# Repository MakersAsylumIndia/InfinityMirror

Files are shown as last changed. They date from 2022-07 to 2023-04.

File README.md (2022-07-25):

# infinity
Circular infinity Mirror project using addressable LED's, based on the [Infinity Mirror designed by Kevin Osbock at WyoLum](https://github.com/wyolum/infinity). Can also be ued as an awesome Coaster, if a 5V source can be embedded in it.

- The /fabricate folder has a FreeCAD file that is parametric - you can choose some of the major dimensions.
- The default settings is for a 200 mm long LED strip.
- The layer stack consists of (top to bottom):
-- Front bezel, which is optional, but gives a better visual result and protects the front mirror.
-- Front Mirror, which is one way or transluscent or whatever is the appropriate terminology (50% transmittance and 50% reflectance).
-- A stack of rings, whose total height is equal or greater than the width of the LED strip.
-- Back mirror, 100% transmittance.
-- Back support plate.
-- A stack of plates to enclose the microcontroller board. The cutout in the plates, and the number of plates needed depends on the size and height of the microcontroller PCB.
-- A final back cover plate. 

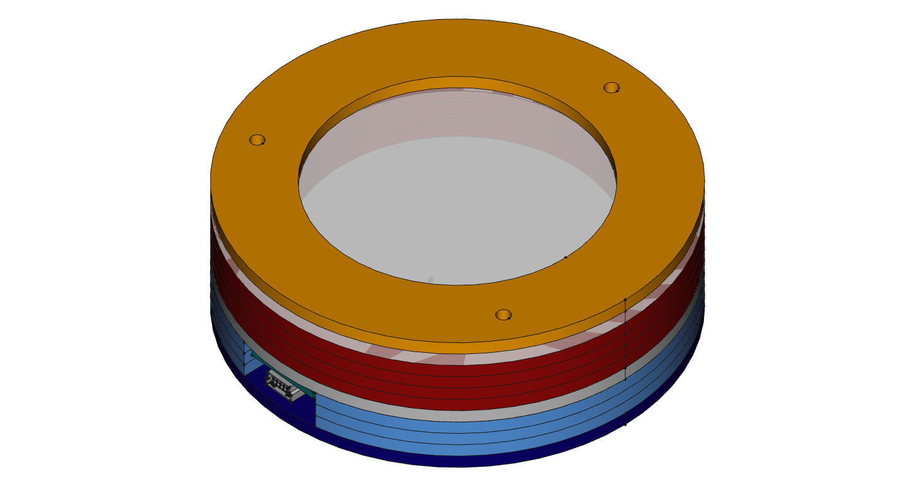
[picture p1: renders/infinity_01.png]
Infinity_Mirror_01

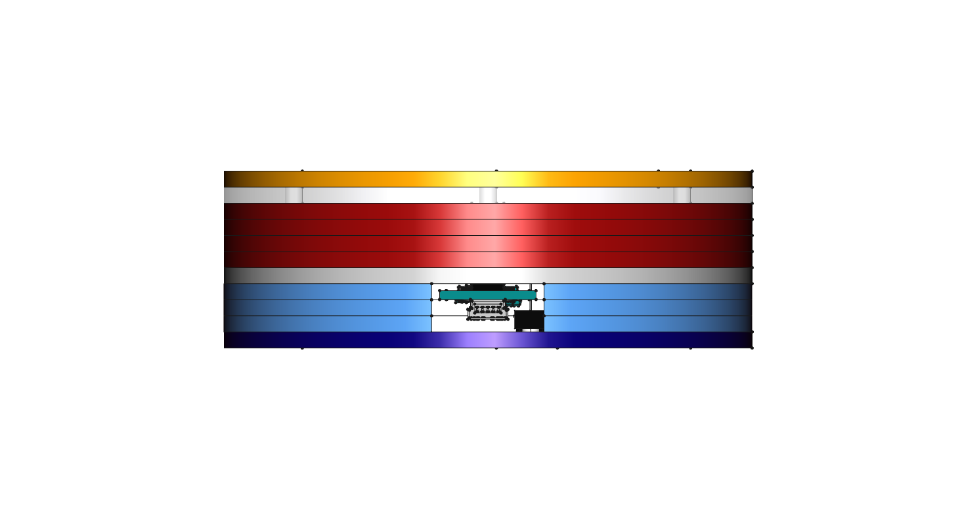
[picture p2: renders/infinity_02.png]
Infinity_Mirror_02

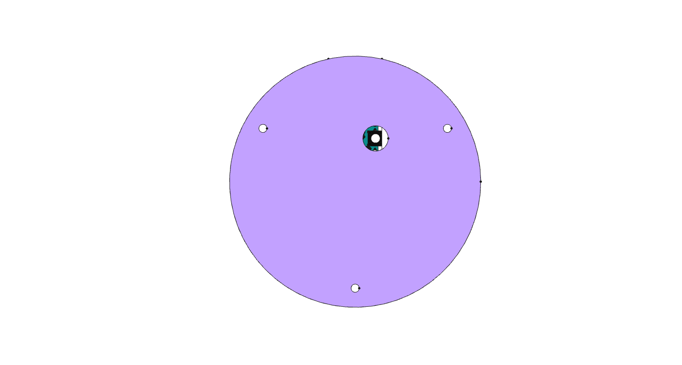
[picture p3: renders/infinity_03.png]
Infinity_Mirror_03


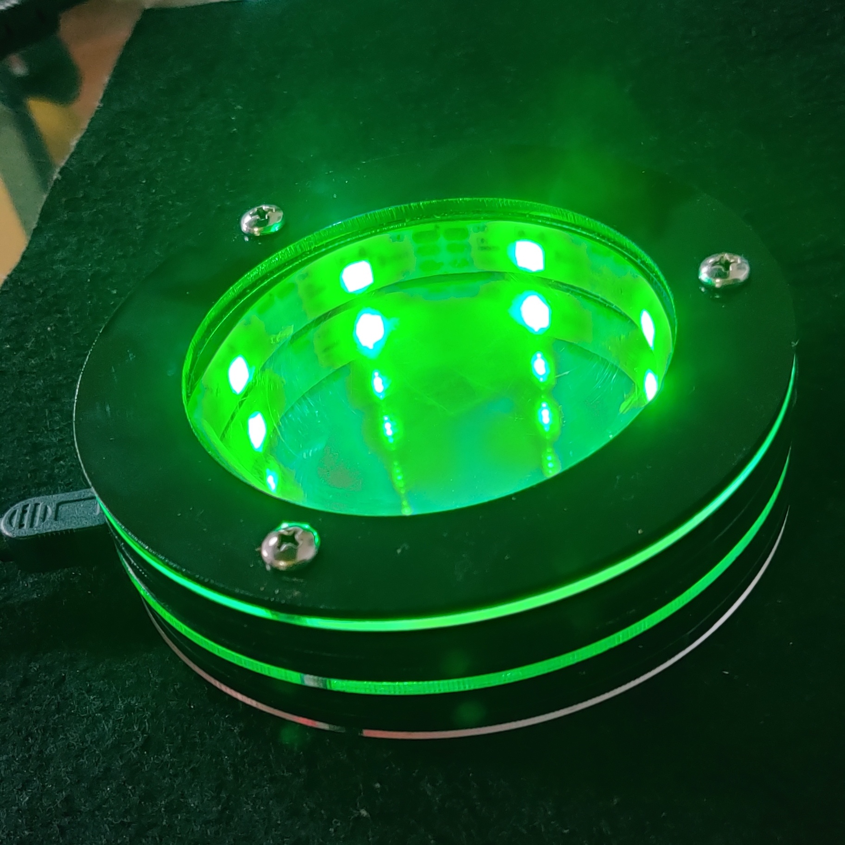
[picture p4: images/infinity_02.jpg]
Infinity_Mirror_04

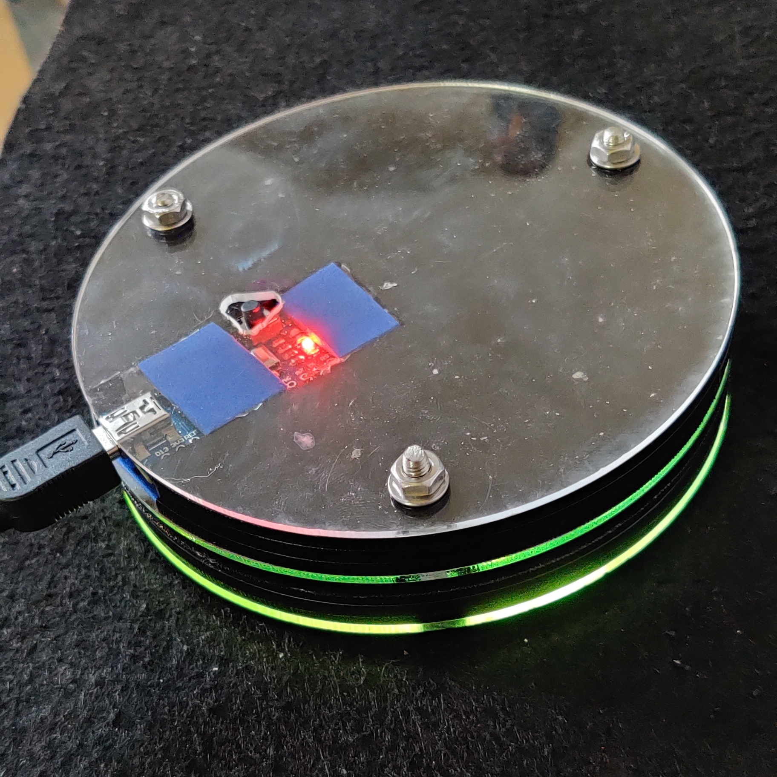
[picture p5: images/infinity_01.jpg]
Infinity_Mirror_05


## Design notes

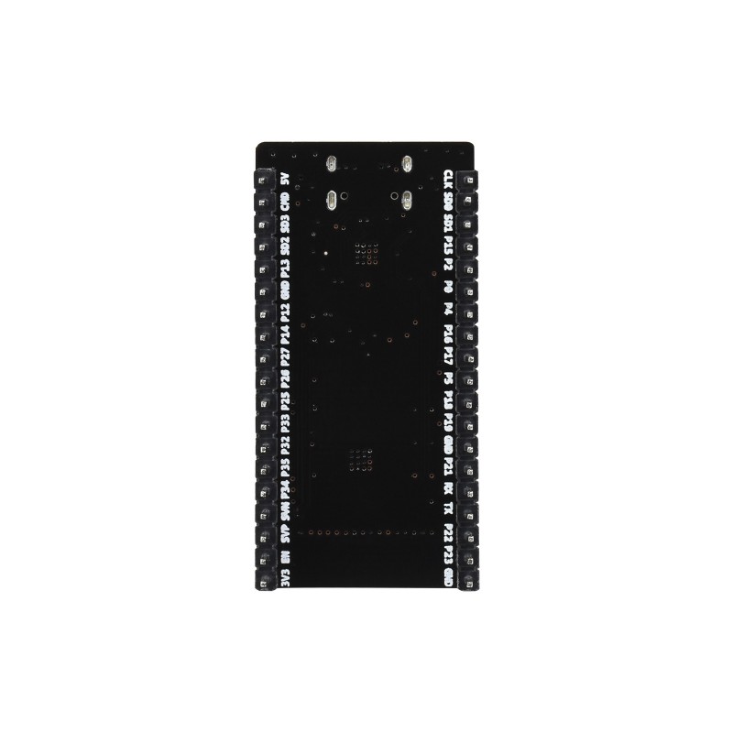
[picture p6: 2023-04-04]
kicad/datasheets/nodemcu-32s-5.jpg

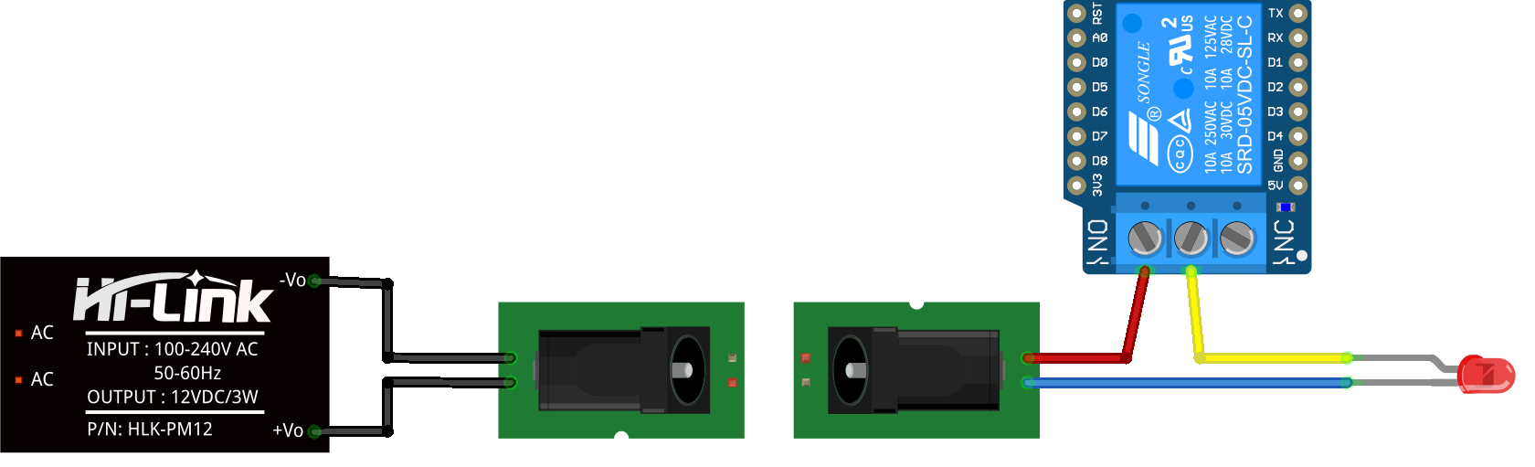
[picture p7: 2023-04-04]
kicad/datasheets/IoT_lamp_12V_LED_02.png

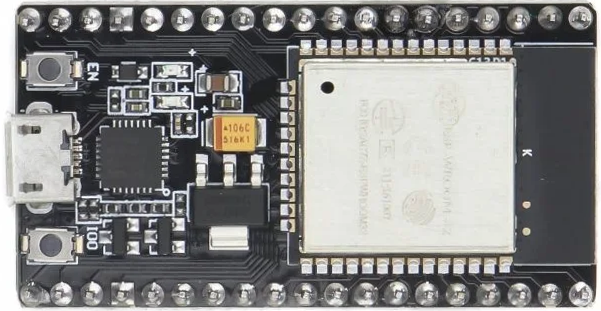
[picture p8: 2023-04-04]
kicad/datasheets/ESP-WROOM-32-MCU-Module3-768x768-1.png

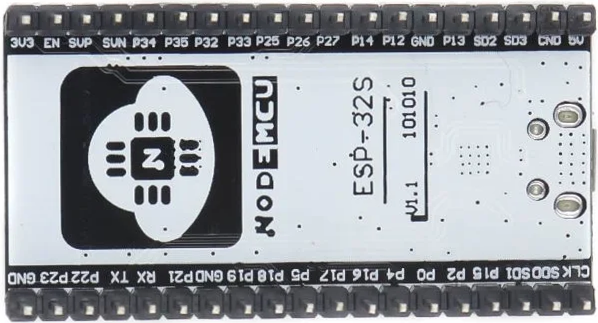
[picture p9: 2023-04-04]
kicad/datasheets/ESP-WROOM-32-MCU-Module4-768x768-1.png

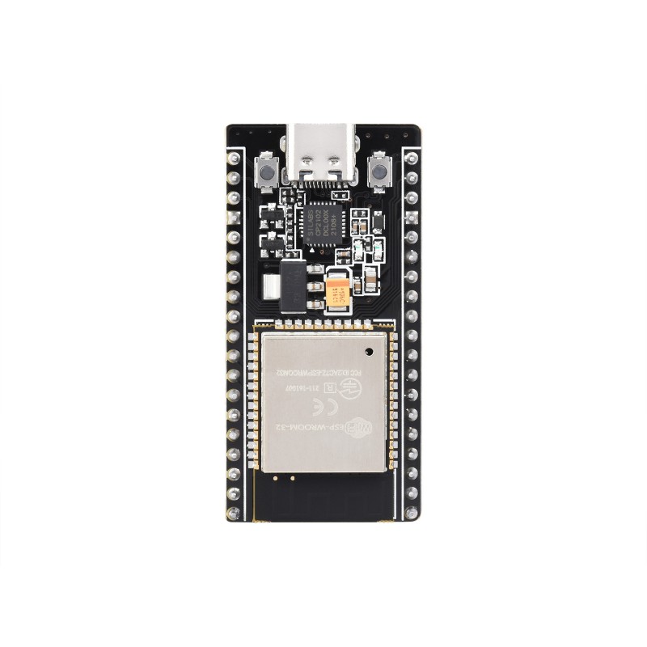
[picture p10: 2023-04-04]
kicad/datasheets/nodemcu-32s-4_4.jpg

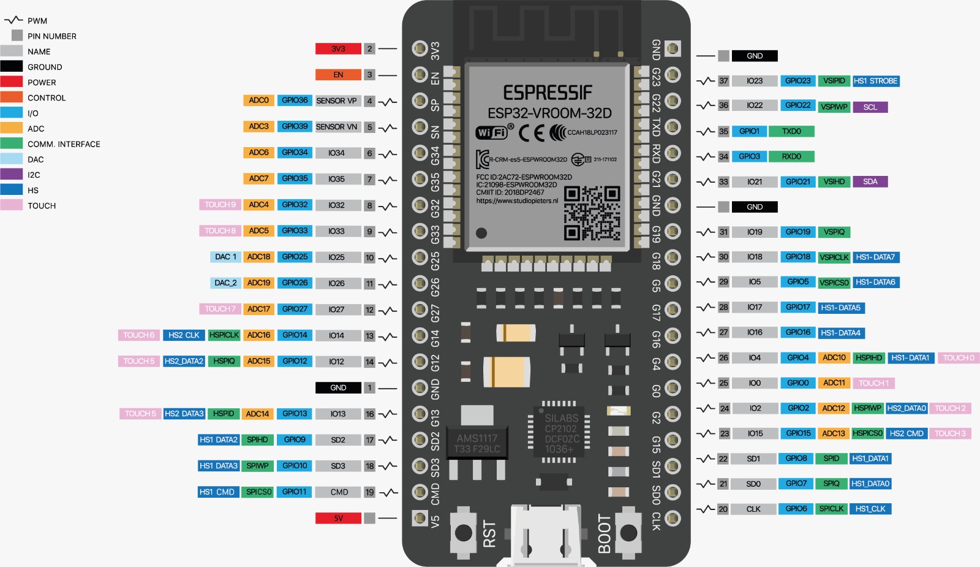
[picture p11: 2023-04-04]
kicad/datasheets/ESP32_VROOM_32D.jpeg

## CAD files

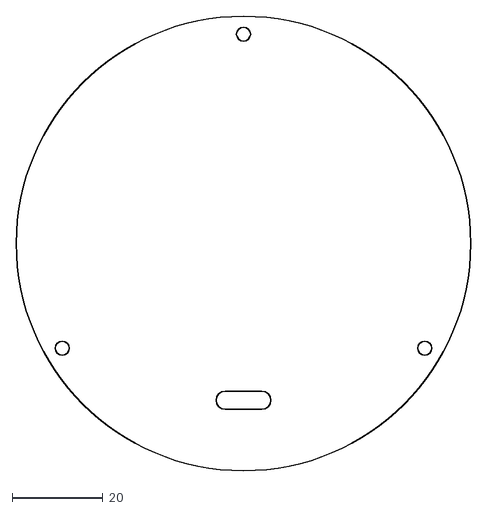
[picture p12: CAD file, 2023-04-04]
fabricate/Infinity_02_DXF/infinity_02-mirror_main.dxf
100.0 x 100.0

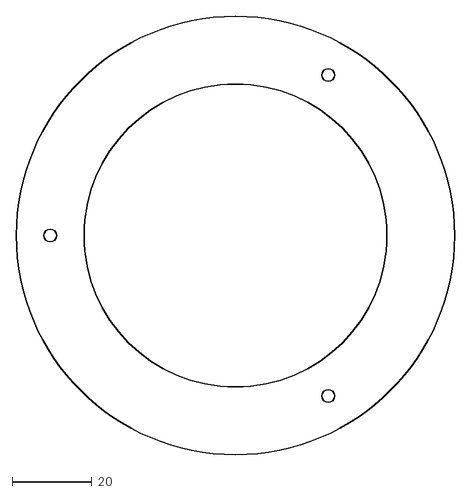
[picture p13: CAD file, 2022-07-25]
fabricate/DXF_anool/bezel.dxf
110.0 x 110.0

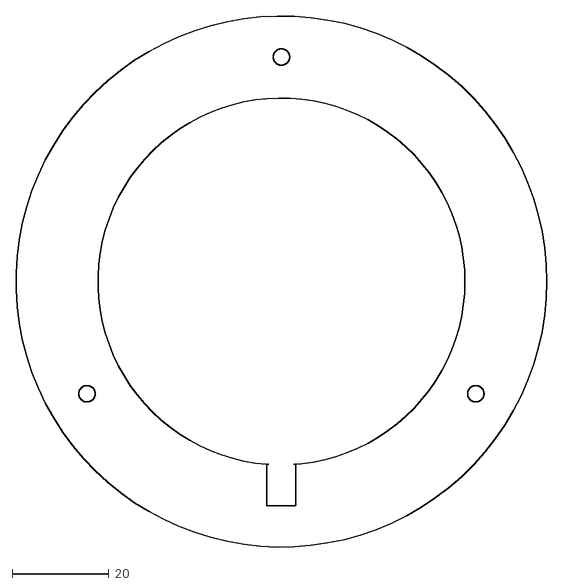
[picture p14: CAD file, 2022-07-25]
fabricate/DXF_SVG_kevin/spacer.dxf
110.0 x 110.0

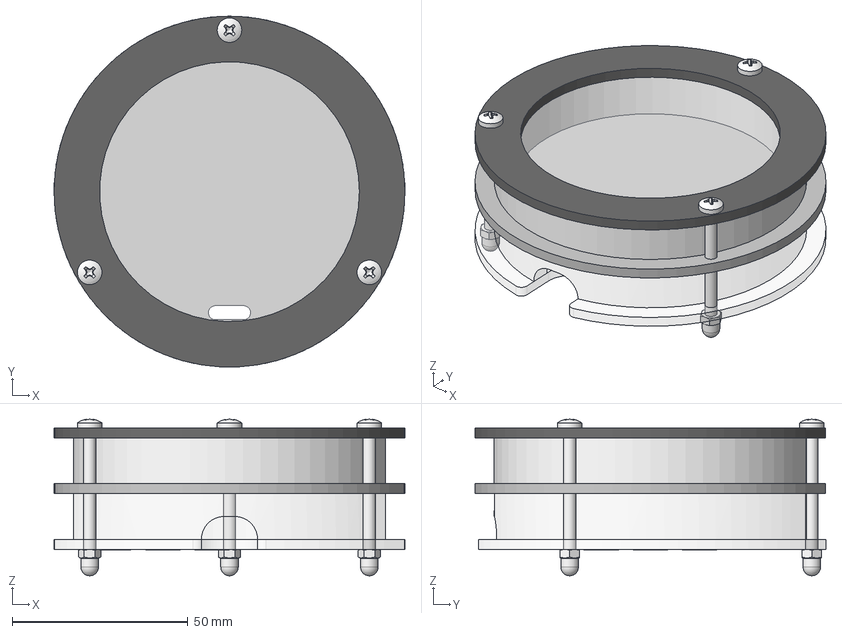
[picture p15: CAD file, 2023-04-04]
fabricate/infinity_02.FCStd
100.0 x 99.9 x 44.6 mm
PCB_lower_spacer
Mirror
Upper_spacer
Mirror_one_way
Front_bezel
Back_cover
Copper_pads
(M3.5)x38-Screw
(M3.5)x38-Screw279
(M3.5)x38-Screw280
M3-Nut
M3-Nut433
M3-Nut434

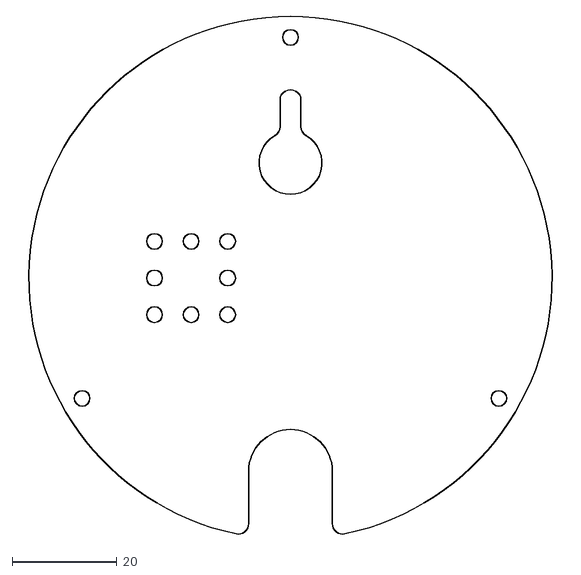
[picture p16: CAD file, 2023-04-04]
fabricate/Infinity_02_DXF/infinity_02-Back_cover.dxf
104.8 x 99.0

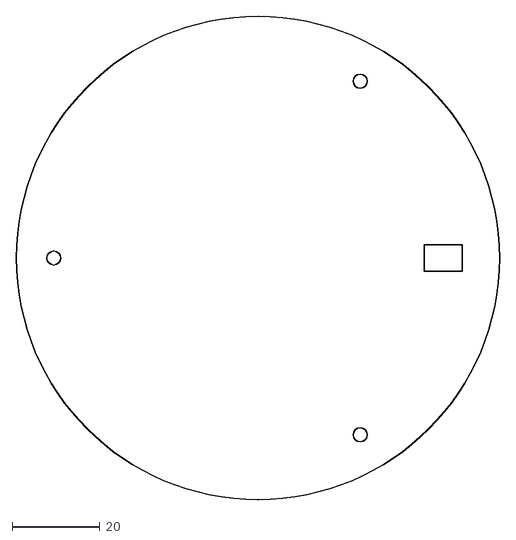
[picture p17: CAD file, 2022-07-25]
fabricate/DXF_anool/back_mirror.dxf
110.0 x 110.0

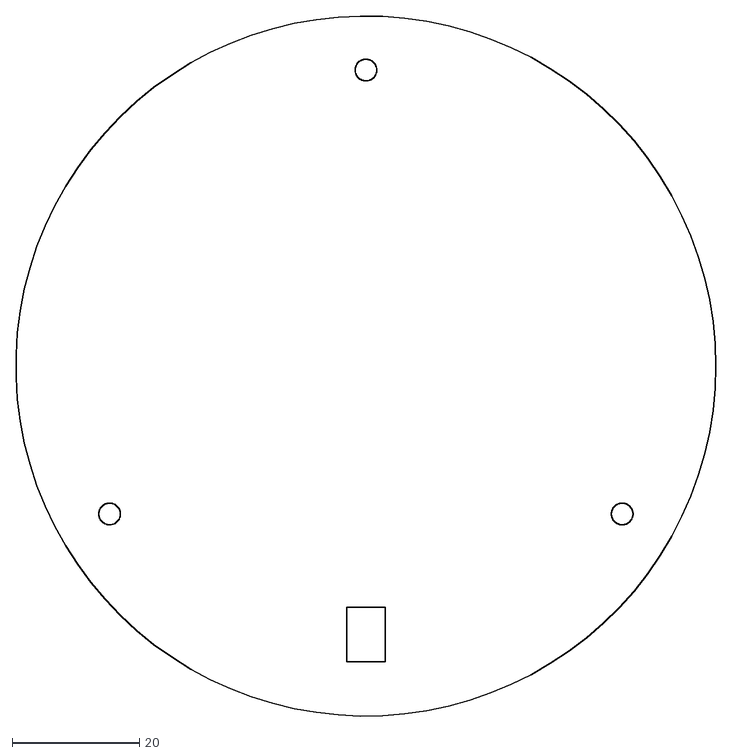
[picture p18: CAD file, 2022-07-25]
fabricate/DXF_SVG_kevin/back_mirror.dxf
110.0 x 110.0

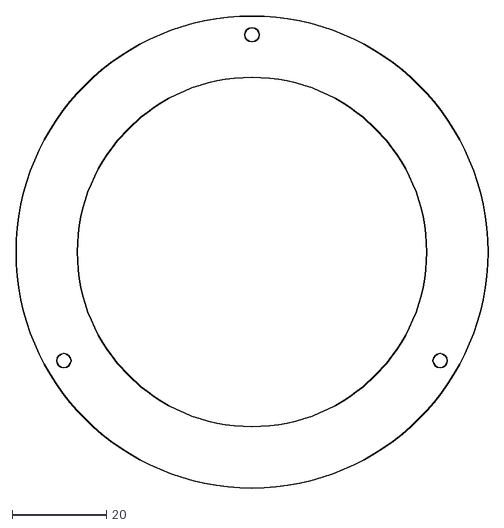
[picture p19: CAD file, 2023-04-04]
fabricate/Infinity_02_DXF/infinity_02-Front_bezel.dxf
100.0 x 100.0

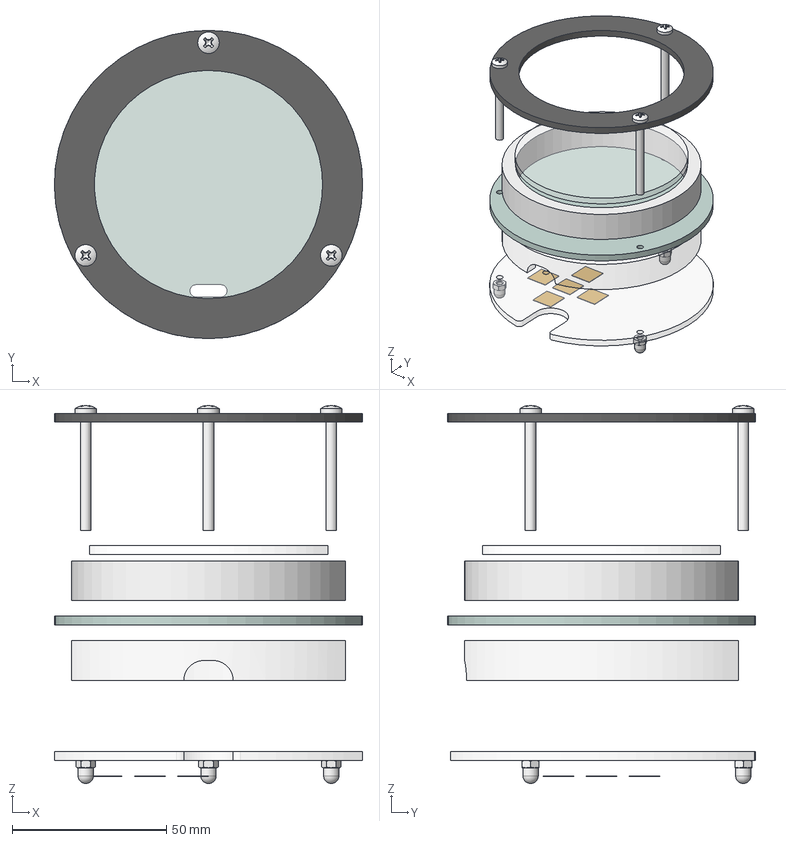
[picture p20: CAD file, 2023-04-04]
fabricate/infinity_02_exploded.FCStd
100.0 x 100.0 x 122.6 mm
PCB_lower_spacer
Mirror
Upper_spacer
Mirror_one_way
Front_bezel
Back_cover
Copper_pads
(M3.5)x38-Screw
(M3.5)x38-Screw309
(M3.5)x38-Screw310
M3-Nut
M3-Nut447
M3-Nut448

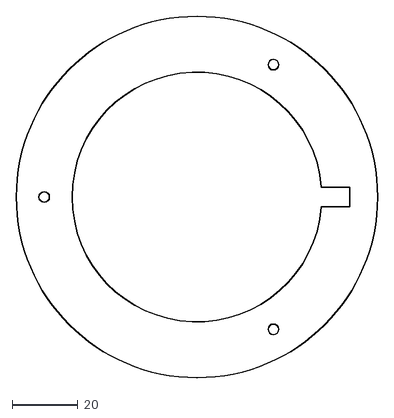
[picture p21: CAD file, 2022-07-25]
fabricate/DXF_anool/spacer_3nos.dxf
110.0 x 110.0

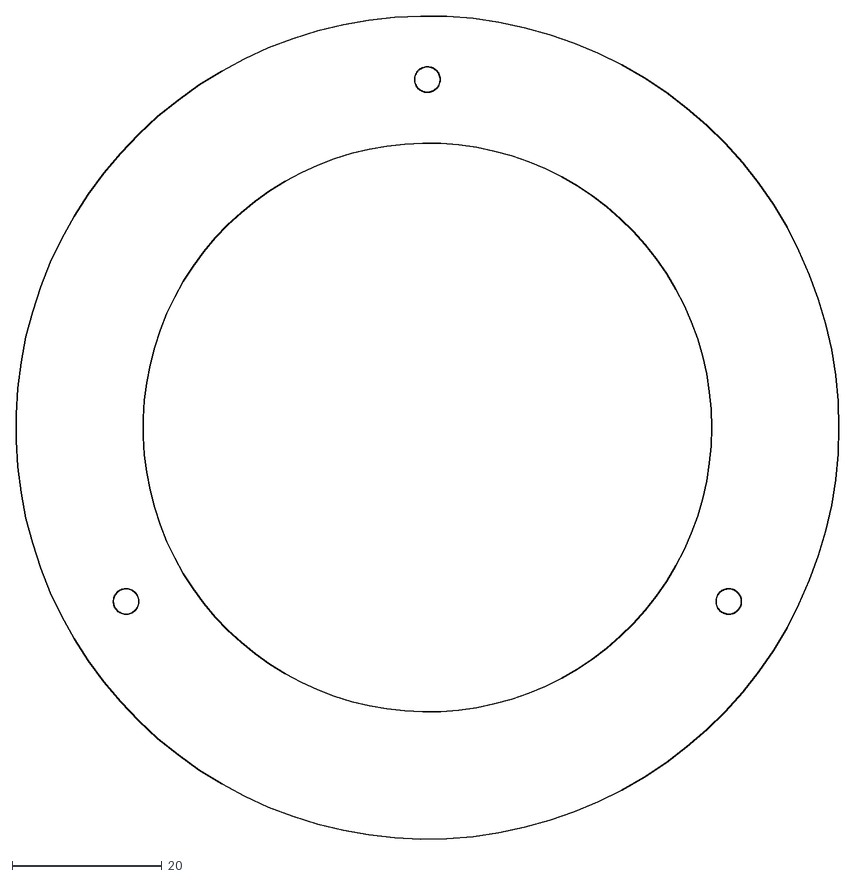
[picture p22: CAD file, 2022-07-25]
fabricate/DXF_SVG_kevin/bezel.dxf
110.0 x 110.0

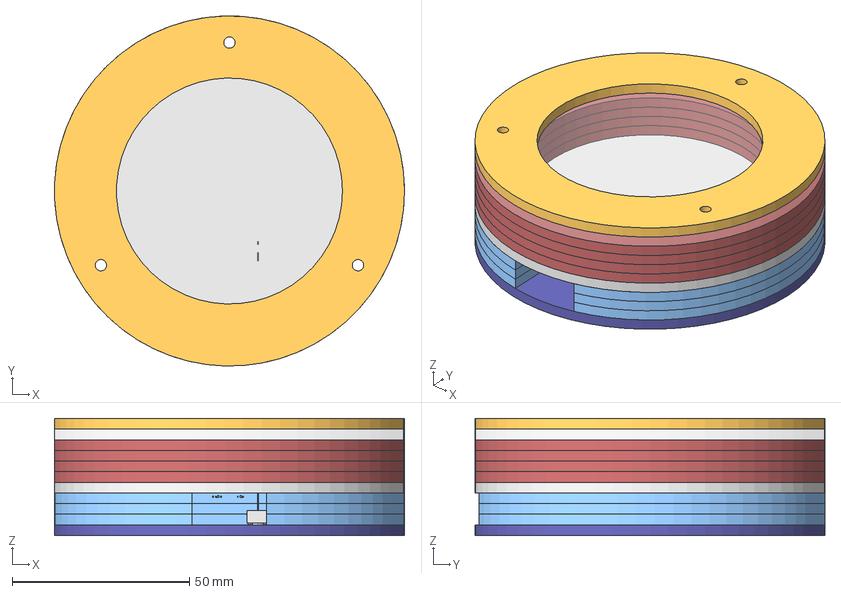
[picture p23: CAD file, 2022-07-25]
fabricate/infinity_01.FCStd
98.7 x 98.7 x 33.0 mm
front_mirror_50%
spacer01
bezel
spacer02
spacer03
back_mirror_100%
arduino_micro_back001
arduino_micro_back002
Component3(Mirror) x 15
Component5(Mirror) x 3
Component5(Mirror) (1) x 3
b3f-6000
spacer04
arduino_micro_back003
back

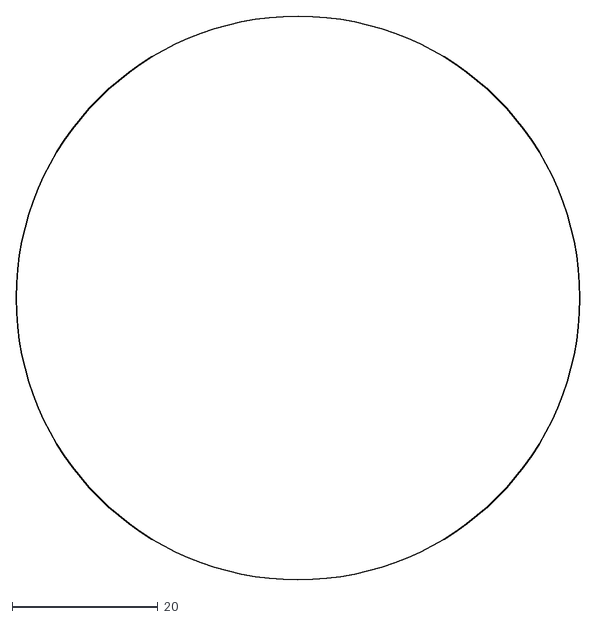
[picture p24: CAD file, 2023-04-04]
fabricate/Infinity_02_DXF/infinity_02-mirror_one_way.dxf
77.4 x 77.4

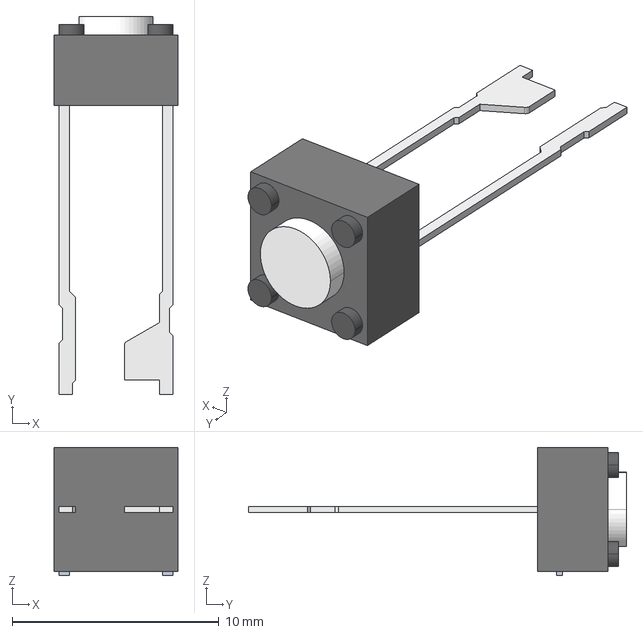
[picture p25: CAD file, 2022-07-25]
fabricate/b3f-6000.step
6.00 x 18.3 x 6.20 mm

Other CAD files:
fabricate/DXF_anool/mirror_2nos.dxf
fabricate/DXF_SVG_kevin/arduino_micro_back.dxf
fabricate/arduino_nano.step
fabricate/DXF_anool/arduino_nano_back.dxf
fabricate/DXF_SVG_kevin/front_mirror.dxf
fabricate/DXF_anool/arduino_micro_back.dxf
fabricate/DXF_anool/back.dxf
fabricate/archive/DXF_SVG_kevin/arduino_micro_back.dxf
fabricate/archive/DXF_SVG_kevin/front_mirror.dxf
fabricate/archive/DXF_anool/arduino_micro_back.dxf
fabricate/archive/DXF_anool/arduino_nano_back.dxf
fabricate/archive/DXF_anool/back.dxf
fabricate/archive/DXF_anool/mirror_2nos.dxf
fabricate/archive/arduino_nano.step

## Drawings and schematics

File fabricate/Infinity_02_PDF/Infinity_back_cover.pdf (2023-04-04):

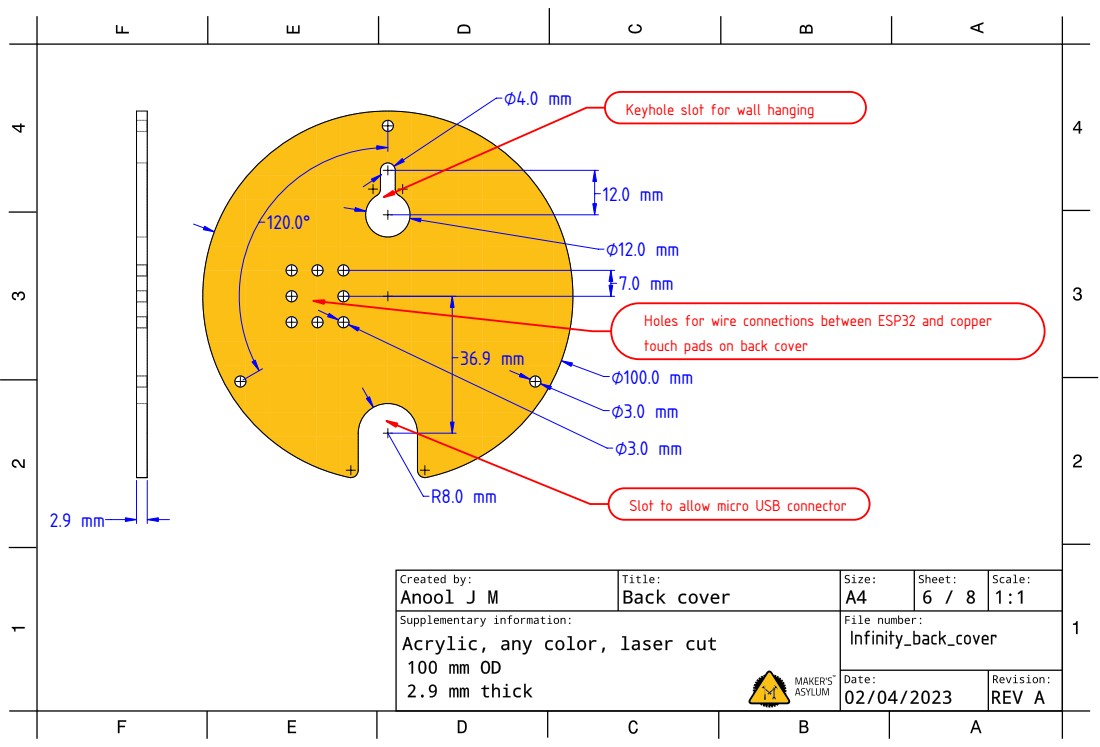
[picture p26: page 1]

Keyhole slot for wall hanging

Holes for wire connections between ESP32 and copper
touch pads on back cover

Slot to allow micro USB connector

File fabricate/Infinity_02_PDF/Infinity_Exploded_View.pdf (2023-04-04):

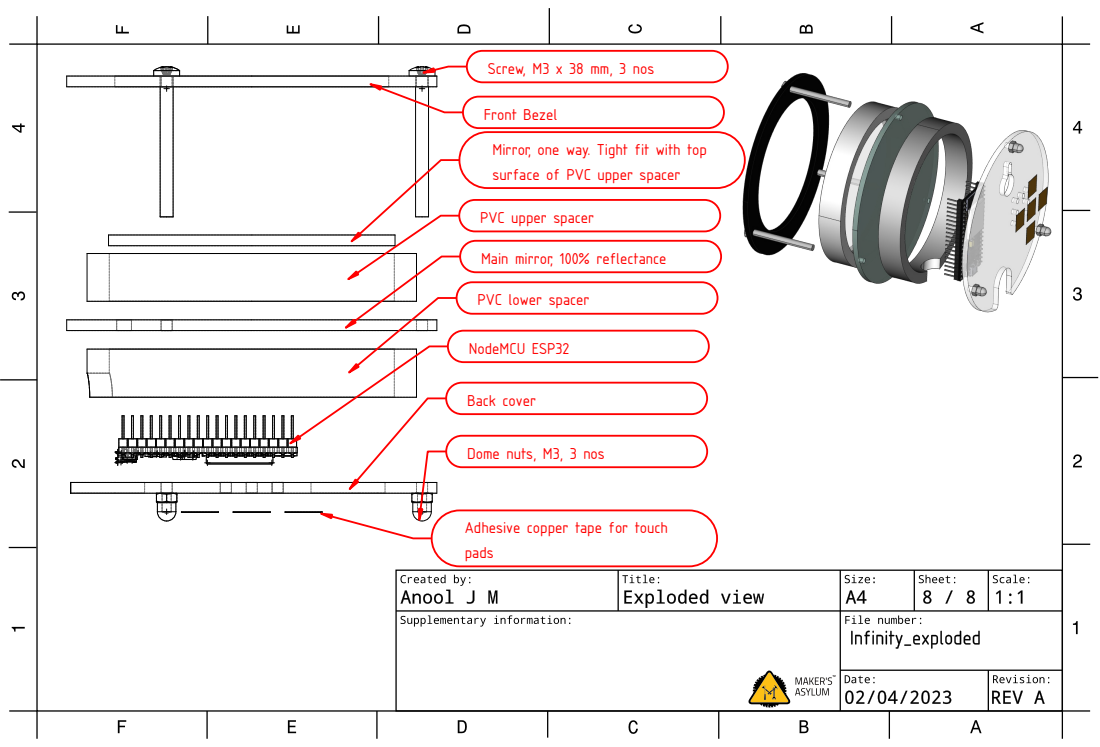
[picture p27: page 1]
NodeMCU ESP32; Back cover

Screw, M3 x 38 mm, 3 nos
Front Bezel
Mirror, one way. Tight fit with top
surface of PVC upper spacer
PVC upper spacer
Main mirror, 100% reflectance
PVC lower spacer

Dome nuts, M3, 3 nos

Adhesive copper tape for touch
pads

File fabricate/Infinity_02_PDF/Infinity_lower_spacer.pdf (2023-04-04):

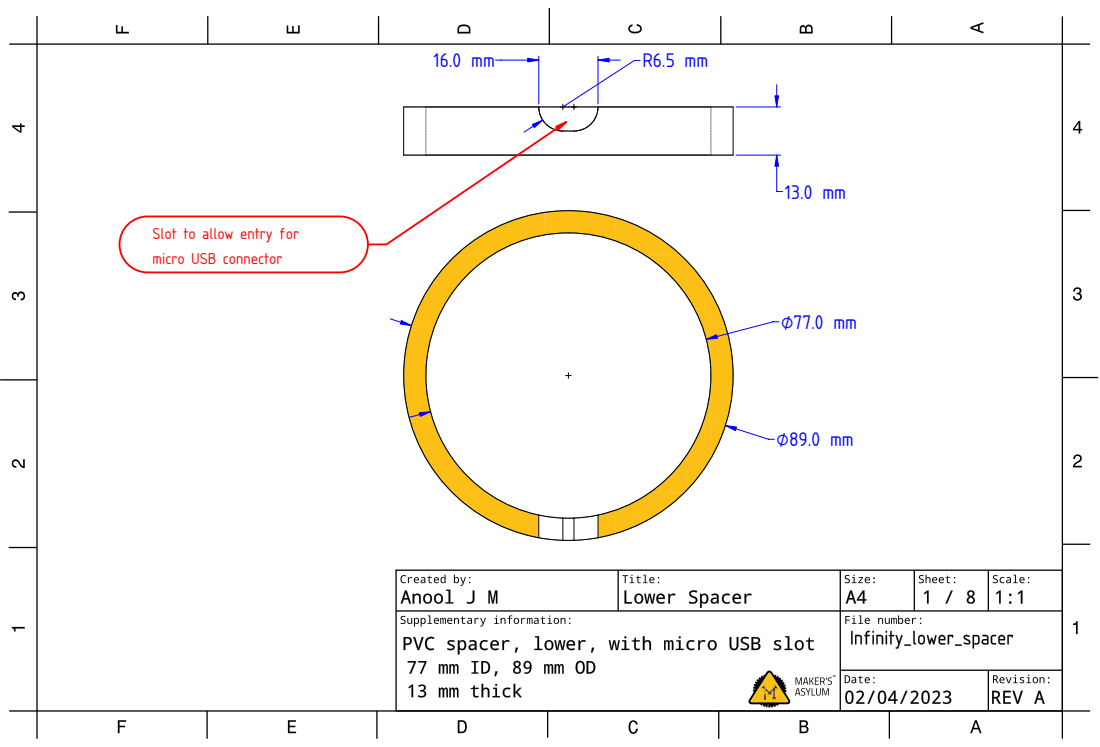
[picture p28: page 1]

Slot to allow entry for
micro USB connector

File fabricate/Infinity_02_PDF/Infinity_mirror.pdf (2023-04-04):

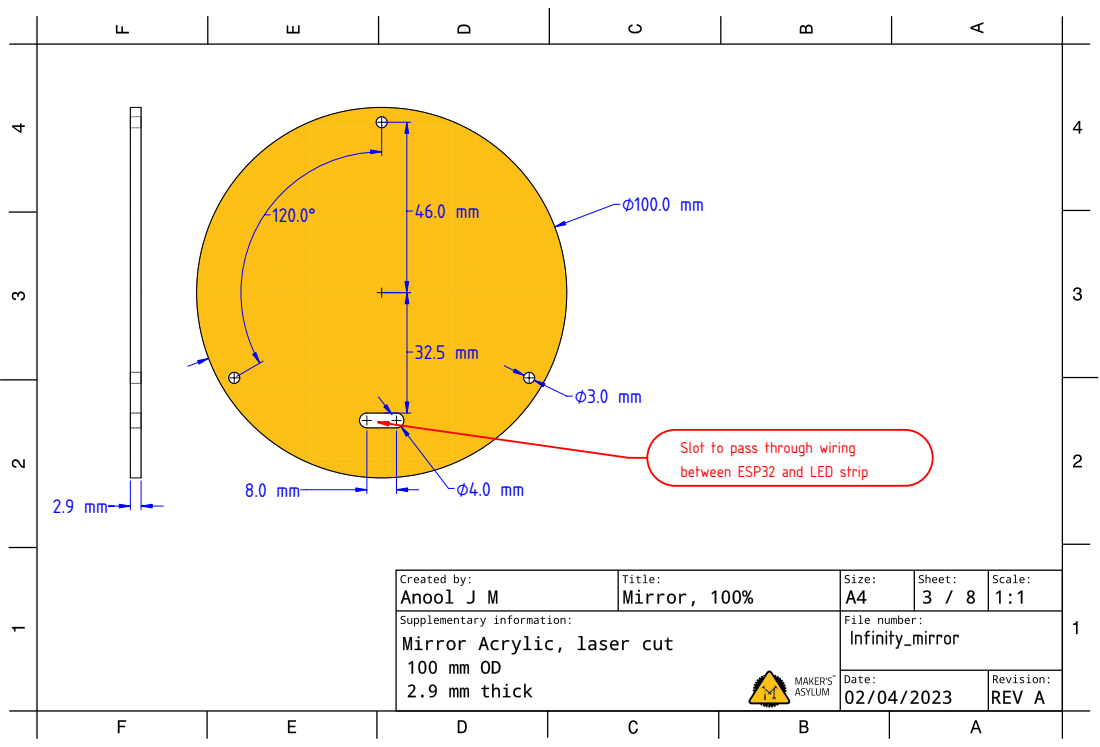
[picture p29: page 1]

Slot to pass through wiring
between ESP32 and LED strip

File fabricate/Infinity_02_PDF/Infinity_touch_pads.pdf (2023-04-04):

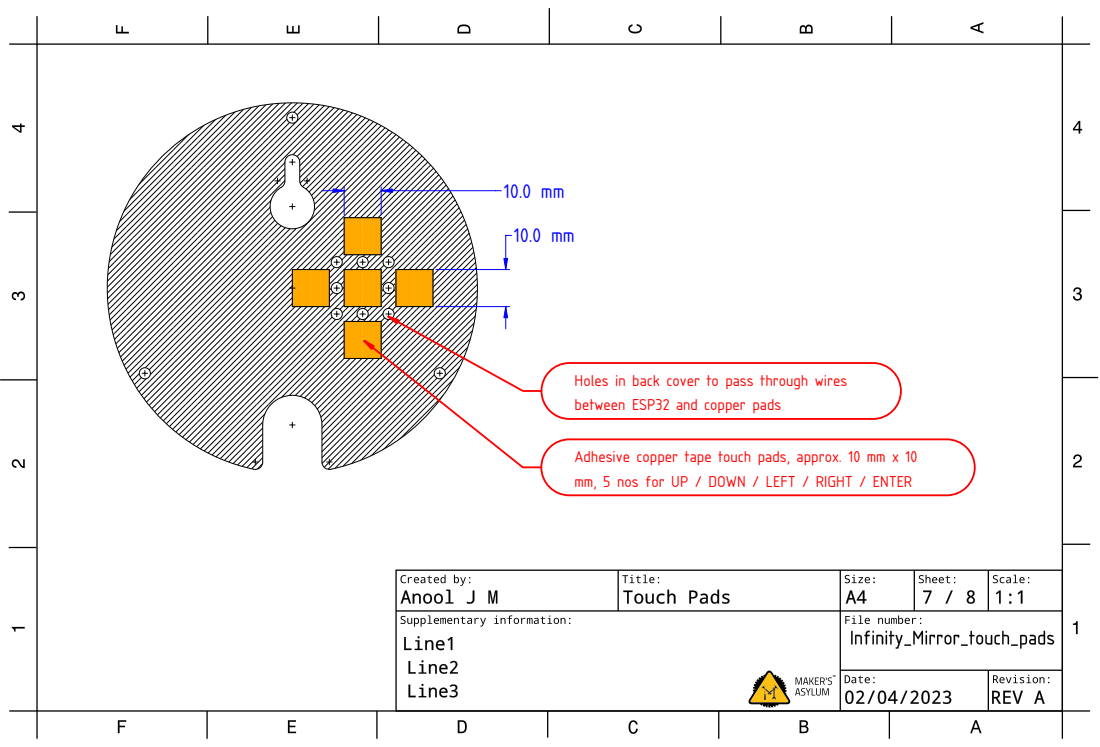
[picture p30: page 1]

Holes in back cover to pass through wires
between ESP32 and copper pads

Adhesive copper tape touch pads, approx. 10 mm x 10
mm, 5 nos for UP / DOWN / LEFT / RIGHT / ENTER

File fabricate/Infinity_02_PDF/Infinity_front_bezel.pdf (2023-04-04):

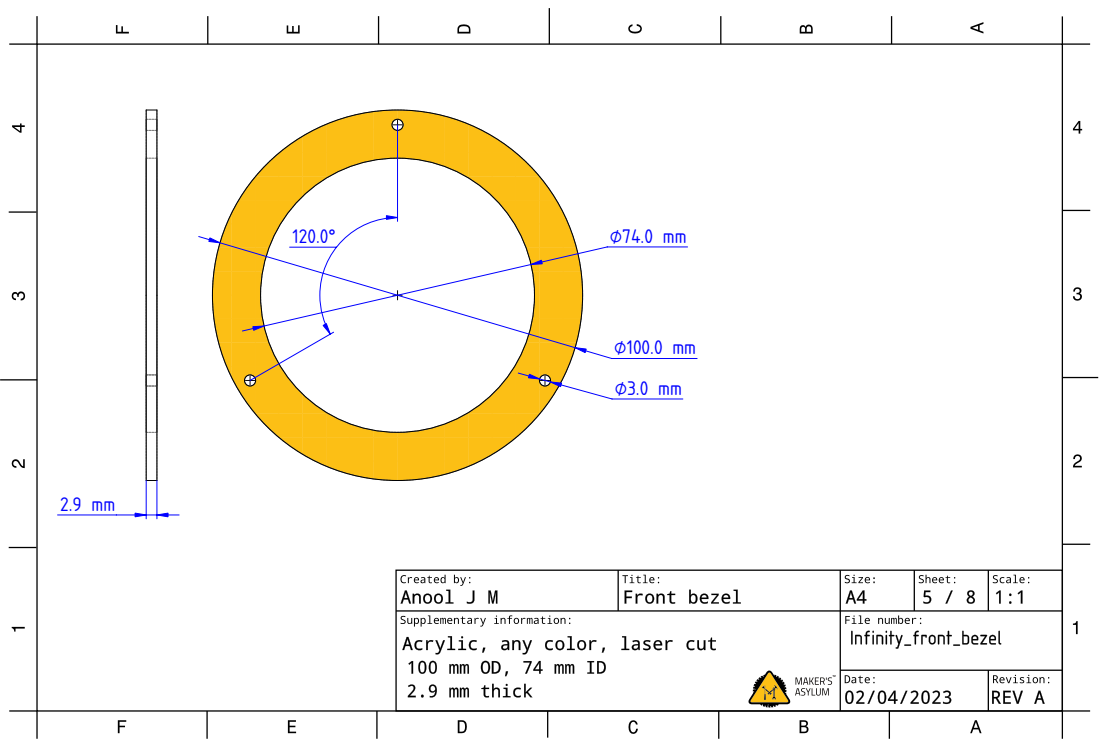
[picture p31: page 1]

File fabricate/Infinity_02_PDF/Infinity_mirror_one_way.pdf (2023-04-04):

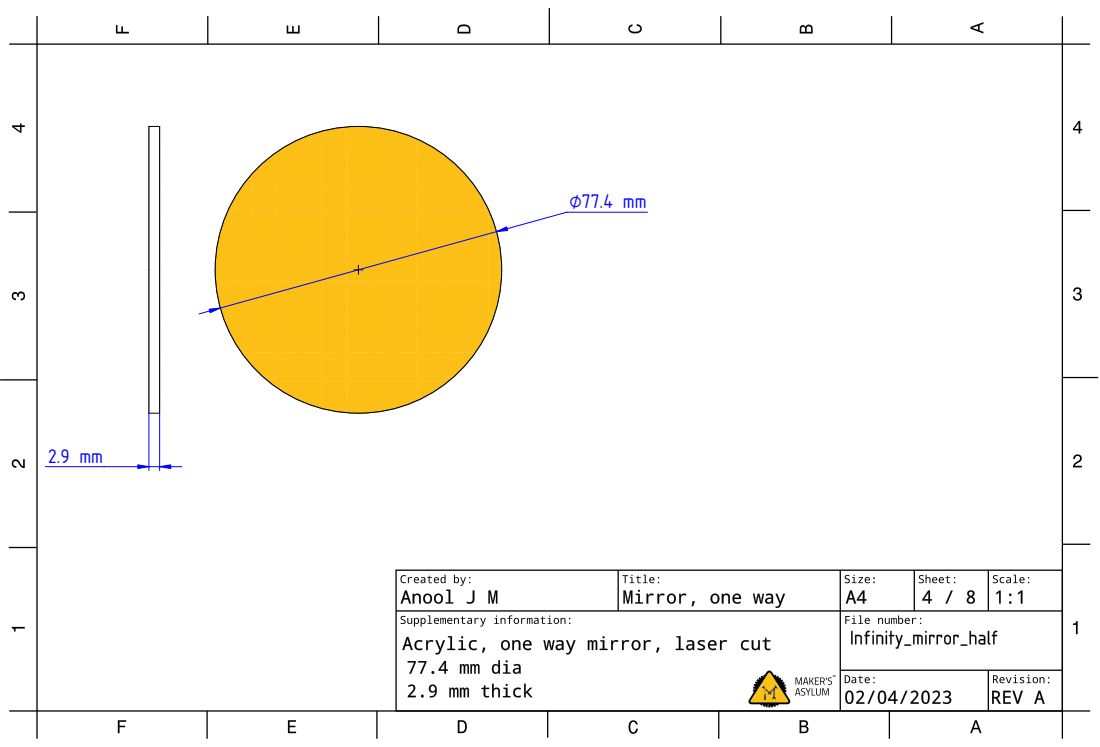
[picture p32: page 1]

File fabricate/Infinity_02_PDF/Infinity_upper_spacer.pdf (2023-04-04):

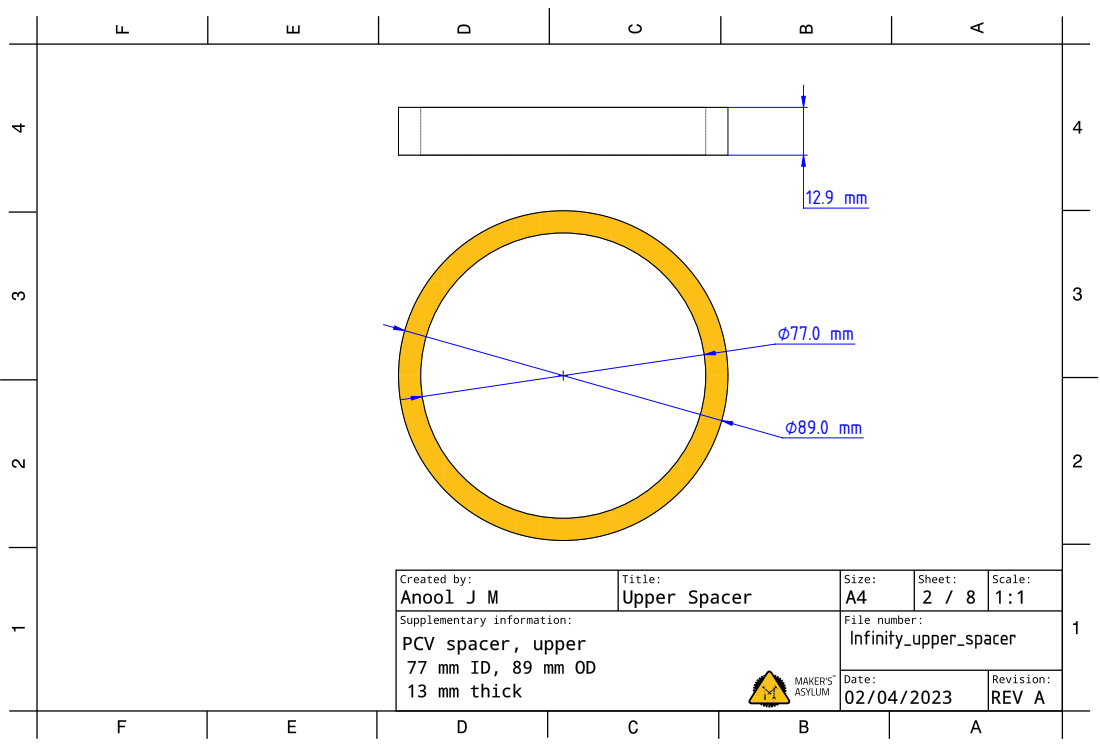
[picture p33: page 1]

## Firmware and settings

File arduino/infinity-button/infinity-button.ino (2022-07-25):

#include <Adafruit_NeoPixel.h>
/* Demo code for infinity mirror. Starts with LED's off
   but switches between modes on button press
*/
#define PIN A2 
#define BUTTONPIN 3

// Parameter 1 = number of pixels in strip
// Parameter 2 = pin number (most are valid)
// Parameter 3 = pixel type flags, add together as needed:
//   NEO_KHZ800  800 KHz bitstream (most NeoPixel products w/WS2812 LEDs)
//   NEO_KHZ400  400 KHz (classic 'v1' (not v2) FLORA pixels, WS2811 drivers)
//   NEO_GRB     Pixels are wired for GRB bitstream (most NeoPixel products)
//   NEO_RGB     Pixels are wired for RGB bitstream (v1 FLORA pixels, not v2)
Adafruit_NeoPixel strip = Adafruit_NeoPixel(7, PIN, NEO_GRB + NEO_KHZ800);
#define NUMMODES 8
int mode;
void setup() {
  pinMode(BUTTONPIN,INPUT);
  digitalWrite(BUTTONPIN,HIGH); //pullup
  strip.begin();
  strip.show(); // Initialize all pixels to 'off'
}

void loop() {
  /*
  // Send a theater pixel chase in...
  theaterChase(strip.Color(127, 127, 127), 50); // White
  theaterChase(strip.Color(127,   0,   0), 50); // Red
  theaterChase(strip.Color(  0,   0, 127), 50); // Blue
  */
  checkButton();
  if(!(mode%2)) //even numbers blank
    blank();
  else if (mode ==1)
    rainbow(20);
  else if (mode ==3)
    rainbowCycle(20);
  else if (mode == 5)
    theaterChaseRainbow(50);
  else if (mode == 7){
    theaterChase(strip.Color(127, 127, 127), 50); // White
    theaterChase(strip.Color(127,   0,   0), 50); // Red
    theaterChase(strip.Color(  0,   0, 127), 50); // Blue
  }
  else
  blank();
}
  
#define BOUNCEDELAY 150
long lastDebounceTime = 0L;
int buttonState = HIGH;
int lastButtonState = HIGH;
boolean checkButton(){
  boolean retval = false;
  if ((millis() -lastDebounceTime) > BOUNCEDELAY){
    int reading = digitalRead(BUTTONPIN);
    if (reading != lastButtonState){
      //reset the debounce timer
      lastDebounceTime = millis();
      if (reading == LOW){
        // advance mode
        mode = mode >=NUMMODES-1?0:mode+1;
        retval = true; 
      }
    }
    lastButtonState = reading;
  }
  return retval;
}
// Fill with black
void blank(){
  for (uint16_t i =0; i < strip.numPixels(); i++)
    strip.setPixelColor(i,0);
  strip.show();
}
// Fill the dots one after the other with a color
void colorWipe(uint32_t c, uint8_t wait) {
  for(uint16_t i=0; i<strip.numPixels(); i++) {
      strip.setPixelColor(i, c);
      strip.show();
      delay(wait);
  }
}

void rainbow(uint8_t wait) {
  uint16_t i, j;

  for(j=0; j<256; j++) {
    for(i=0; i<strip.numPixels(); i++) {
      strip.setPixelColor(i, Wheel((i+j) & 255));
      if (checkButton())
        return;
    }
    strip.show();
    delay(wait);
  }
}

// Slightly different, this makes the rainbow equally distributed throughout
void rainbowCycle(uint8_t wait) {
  uint16_t i, j;

  for(j=0; j<256*5; j++) { // 5 cycles of all colors on wheel
    for(i=0; i< strip.numPixels(); i++) {
      strip.setPixelColor(i, Wheel(((i * 256 / strip.numPixels()) + j) & 255));
      if (checkButton())
        return;
    }
    strip.show();
    delay(wait);
  }
}

//Theatre-style crawling lights.
void theaterChase(uint32_t c, uint8_t wait) {
  for (int j=0; j<10; j++) {  //do 10 cycles of chasing
    for (int q=0; q < 3; q++) {
      for (int i=0; i < strip.numPixels(); i=i+3) {
        strip.setPixelColor(i+q, c);    //turn every third pixel on
        if (checkButton())
          return;
      }
      strip.show();
     
      delay(wait);
     
      for (int i=0; i < strip.numPixels(); i=i+3) {
        strip.setPixelColor(i+q, 0);        //turn every third pixel off
      }
    }
  }
}

//Theatre-style crawling lights with rainbow effect
void theaterChaseRainbow(uint8_t wait) {
  for (int j=0; j < 256; j++) {     // cycle all 256 colors in the wheel
    for (int q=0; q < 3; q++) {
        for (int i=0; i < strip.numPixels(); i=i+3) {
          strip.setPixelColor(i+q, Wheel( (i+j) % 255));    //turn every third pixel on
          if (checkButton())
            return;
        }
        strip.show();
       
        delay(wait);
       
        for (int i=0; i < strip.numPixels(); i=i+3) {
          strip.setPixelColor(i+q, 0);        //turn every third pixel off
        }
    }
  }
}

// Input a value 0 to 255 to get a color value.
// The colours are a transition r - g - b - back to r.
uint32_t Wheel(byte WheelPos) {
  if(WheelPos < 85) {
   return strip.Color(WheelPos * 3, 255 - WheelPos * 3, 0);
  } else if(WheelPos < 170) {
   WheelPos -= 85;
   return strip.Color(255 - WheelPos * 3, 0, WheelPos * 3);
  } else {
   WheelPos -= 170;
   return strip.Color(0, WheelPos * 3, 255 - WheelPos * 3);
  }
}

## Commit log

2022-07-25 added renders and images
    [arduino_micro_back.dxf, arduino_nano.step, arduino_nano_back.dxf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]
2023-04-04 version 02 using NodeMCU ESP32 and PVC pipe spacers
    [ESP32_infinity_mirror.kicad_pcb, ESP32_infinity_mirror.kicad_sch, IoT_lamp_12V_LED.fzz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]
